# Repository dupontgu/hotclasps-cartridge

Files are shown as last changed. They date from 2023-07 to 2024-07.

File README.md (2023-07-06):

# HotClasps (HitClips compatible audio cartridge)
This repository contains the hardware, software, and enclosure CAD for the HotClaps cartridge (and accomanying debugger). It will play any audio through Tiger Electronics' [HitClips](https://en.wikipedia.org/wiki/HitClips) players.

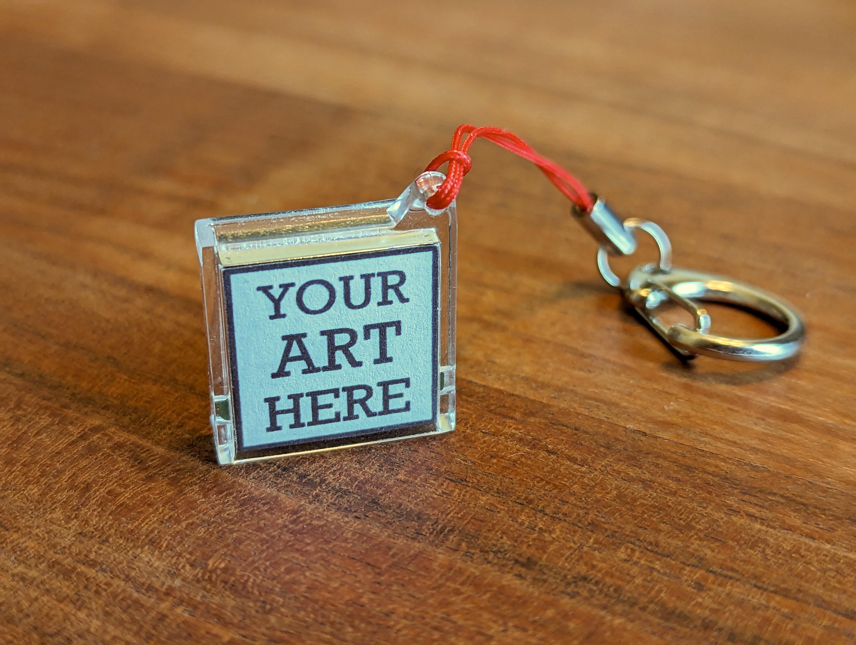
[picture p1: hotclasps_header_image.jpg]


### Context 
This is a complete rebuild of my [Homebrew HitClips](https://hackaday.io/project/183495-homebrew-hitclips) project from 2022.

### Features
* Significantly improved audio quality over the original toys (hard to quantify, but the bar was low).
* Space for ~10 minutes of audio, which can be split across multiple files. This can theoretically be extended if you dial back the audio quality further.
* USB Storage interface for dragging/dropping audio files from a computer.
* [Web application](https://www.hotclasps.com) with tools to convert audio files and print custom artwork for the case. (Source code for web app [here](https://github.com/dupontgu/hc-webapp))

### Notes
* The hardware is built around the Raspberry Pi RP2040 microcontroller.
* The firmware is written in [CircuitPython](https://circuitpython.org/), and features an audio driver written in [pioasm](https://rp2040pio-docs.readthedocs.io/en/latest/pio-programs.html).

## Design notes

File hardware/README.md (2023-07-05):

## Notes
* Cartridge is comprised of two PCBs - the main board, and an adapter which extends the thickness so that the cartridge makes direct contact with a HitClips player.
* Main board should be 0.8mm thick, adapter should be 1.2mm.

Front        |  Back
:-------------------------:|:-------------------------:
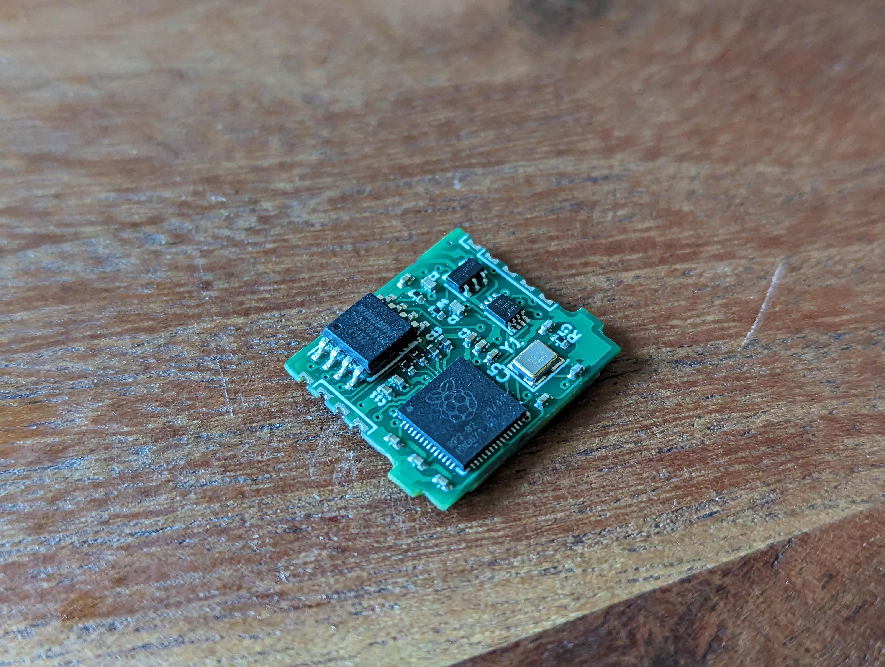
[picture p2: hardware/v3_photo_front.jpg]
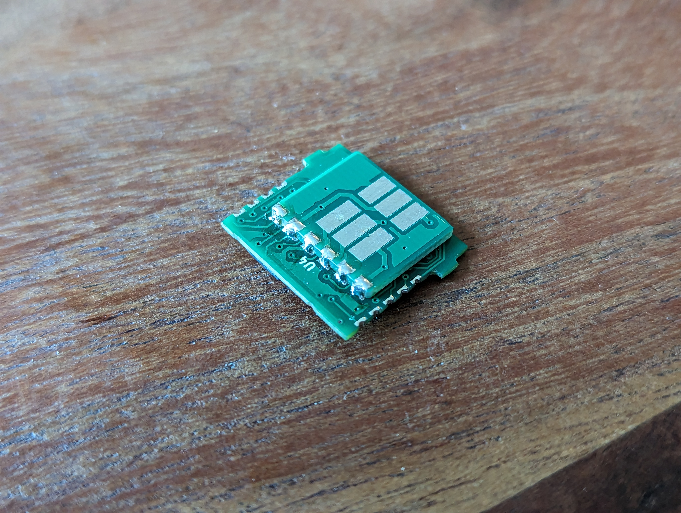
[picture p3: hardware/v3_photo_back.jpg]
  |

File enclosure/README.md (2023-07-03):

## Notes
* Cases are ordered from PCBWAY with their [UTR-8100 transparent resin](https://www.pcbway.com/rapid-prototyping/3d-printing/plastic/resin/UTR-8100/).
* The shim holds the circuit board securely in place within in the case, and also holds the artwork against the case window. It can be 3D printed / milled from any rigid material. (I use FDM-printed PETG)

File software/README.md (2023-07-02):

## Contents

## - `hotclasps_circuitpy_8_1_0.uf2`
This is the "officially" supported build of CircuitPython that runs on the HotClasps cartridge. It is based off of the `8.1.0` release, and simply adds a board definition with proper pin names and USB ids for this device.

## - `code.py`
The firmware for this device, which runs on the build of CircuitPython above. 
### **Notes:**
* This build expects audio files to be converted into the [`.htclp`](https://www.hotclasps.com/upload) format and loaded into a directory named `sounds`.
* CircuitPython dependencies:
    * [adafruit_pioasm](https://github.com/adafruit/Adafruit_CircuitPython_PIOASM)
    * [adafruit_ticks](https://github.com/adafruit/Adafruit_CircuitPython_Ticks)
    * [asyncio](https://github.com/adafruit/Adafruit_CircuitPython_asyncio)

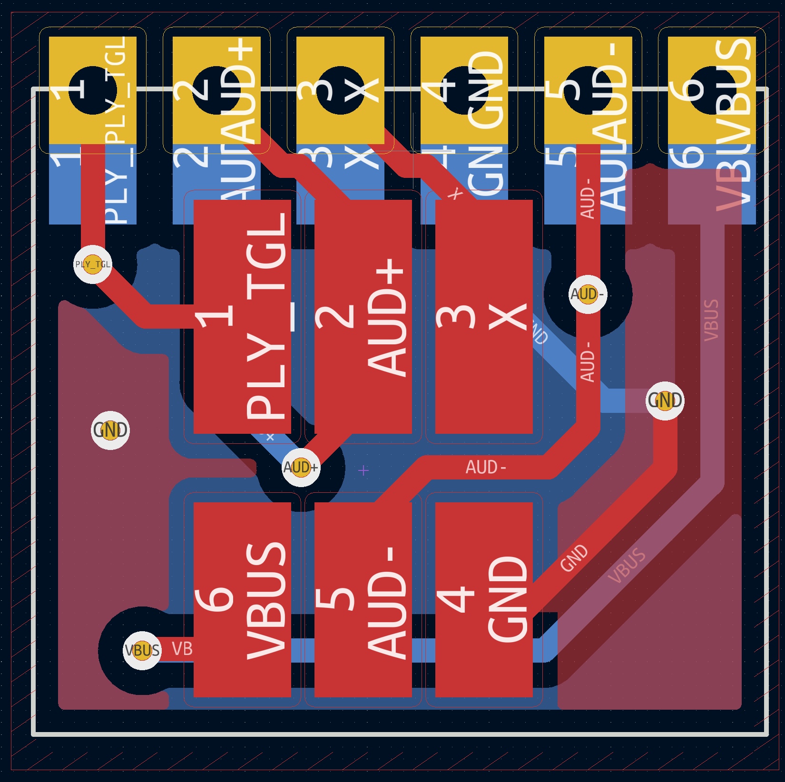
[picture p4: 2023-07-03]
hardware/hotclasps_v3_adapter.jpg

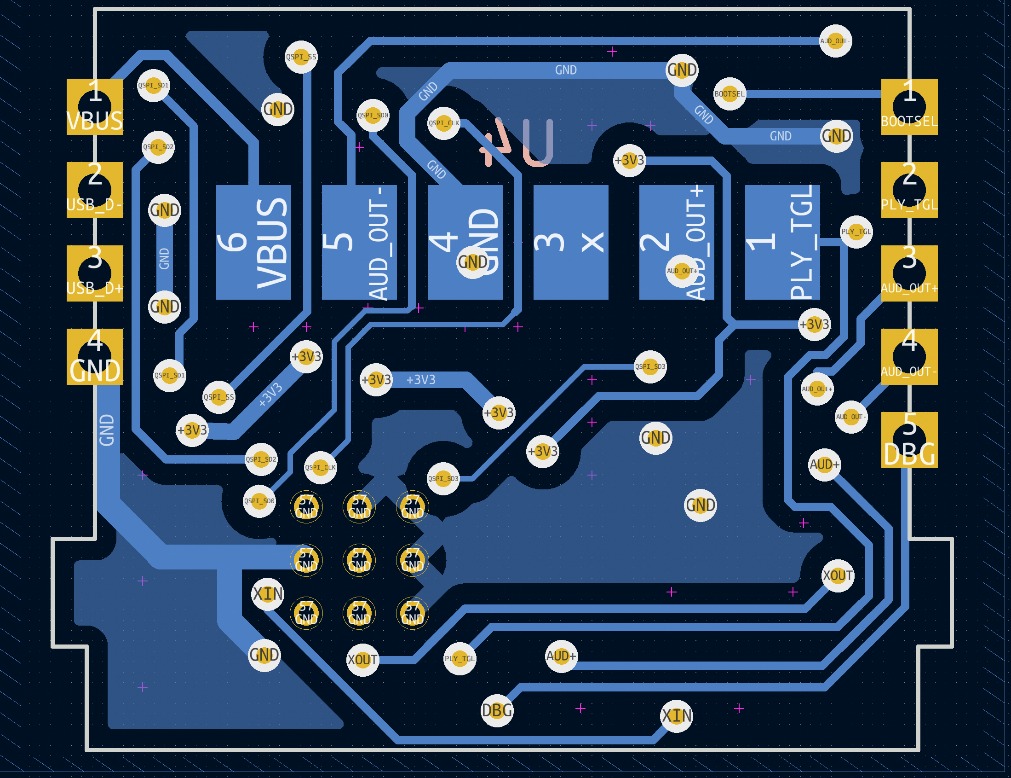
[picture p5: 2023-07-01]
hardware/hotclasps_v3_brd_back.png

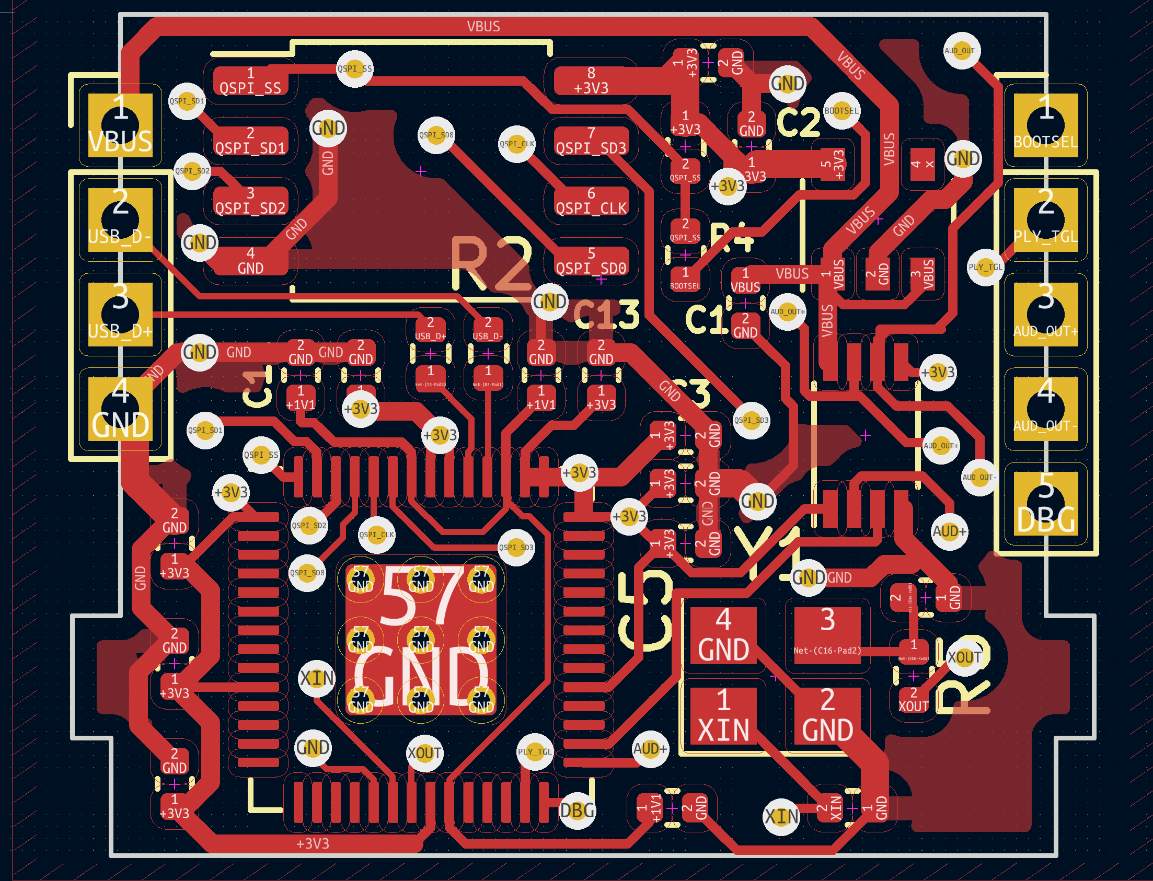
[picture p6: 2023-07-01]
hardware/hotclasps_v3_brd_front.png

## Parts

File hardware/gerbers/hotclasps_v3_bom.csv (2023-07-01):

Designator | Footprint | Comment
U2 | SOIC-8_5.23x5.23mm_P1.27mm | W25Q128JVS
C14,C9,C11,C5,C7,C3,C6,C4,C10,C8 | C_0402_1005Metric | 100n
R3 | R_0402_1005Metric | 10k
R5,R4 | R_0402_1005Metric | 1k
R1,R2 | R_0402_1005Metric | 27.4
C15,C16 | C_0402_1005Metric | 27p
U1 | TSOP-5_1.65x3.05mm_P0.95mm | NCP511SN33T1G
C13,C12 | C_0402_1005Metric | 1u
Y1 | Crystal_SMD_3225-4Pin_3.2x2.5mm | Crystal_GND24_Small
J1 | PinHeader_1x04_P2.00mm_Vertical | Conn_01x04_Male
C1,C2 | C_0402_1005Metric | 10u
U3 | RP2040-QFN-56 | RP2040
U5 | VSSOP-8_2.3x2mm_P0.5mm | 74LVCH2T45DC
J2 | PinHeader_1x05_P2.00mm_Vertical | Conn_01x05_Male
U4 | hitclip_2040_rcv | hitclip_6

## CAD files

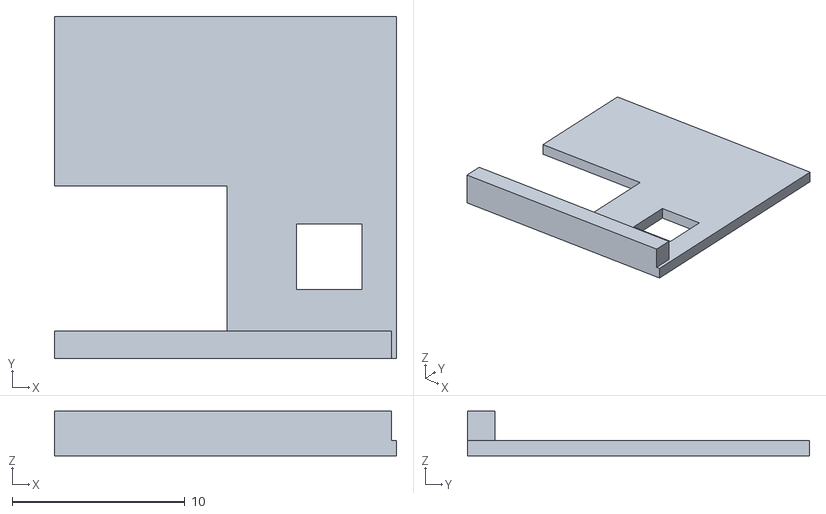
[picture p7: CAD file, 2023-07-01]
enclosure/hotclasps_shim_v2.stl
19.8 x 19.8 x 2.60

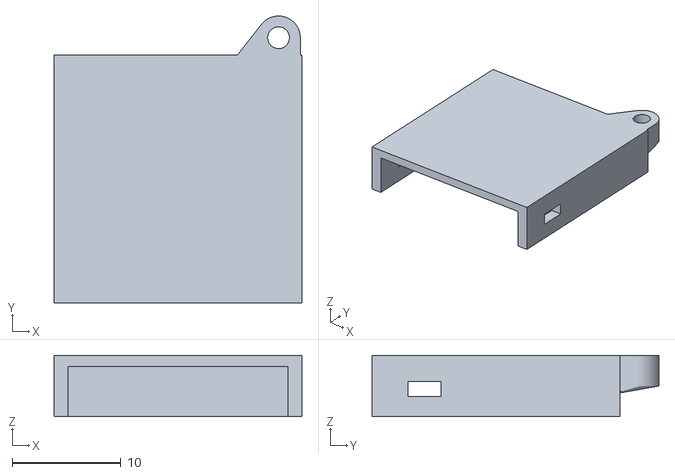
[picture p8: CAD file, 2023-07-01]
enclosure/hotclasps_case_v3.stl
22.8 x 26.4 x 5.63

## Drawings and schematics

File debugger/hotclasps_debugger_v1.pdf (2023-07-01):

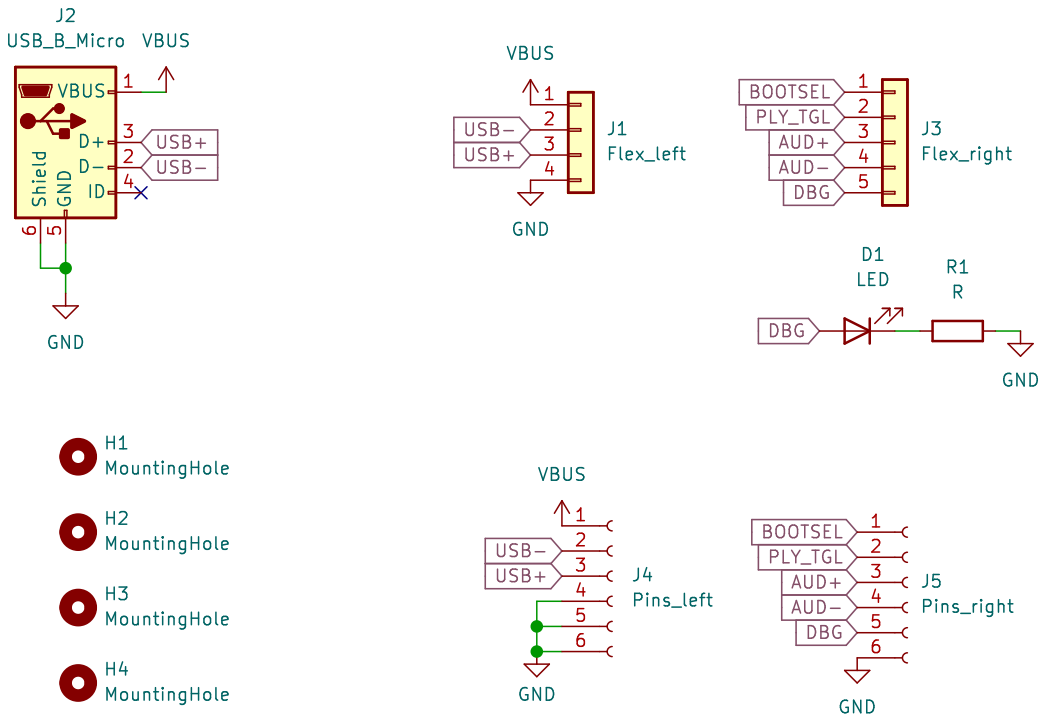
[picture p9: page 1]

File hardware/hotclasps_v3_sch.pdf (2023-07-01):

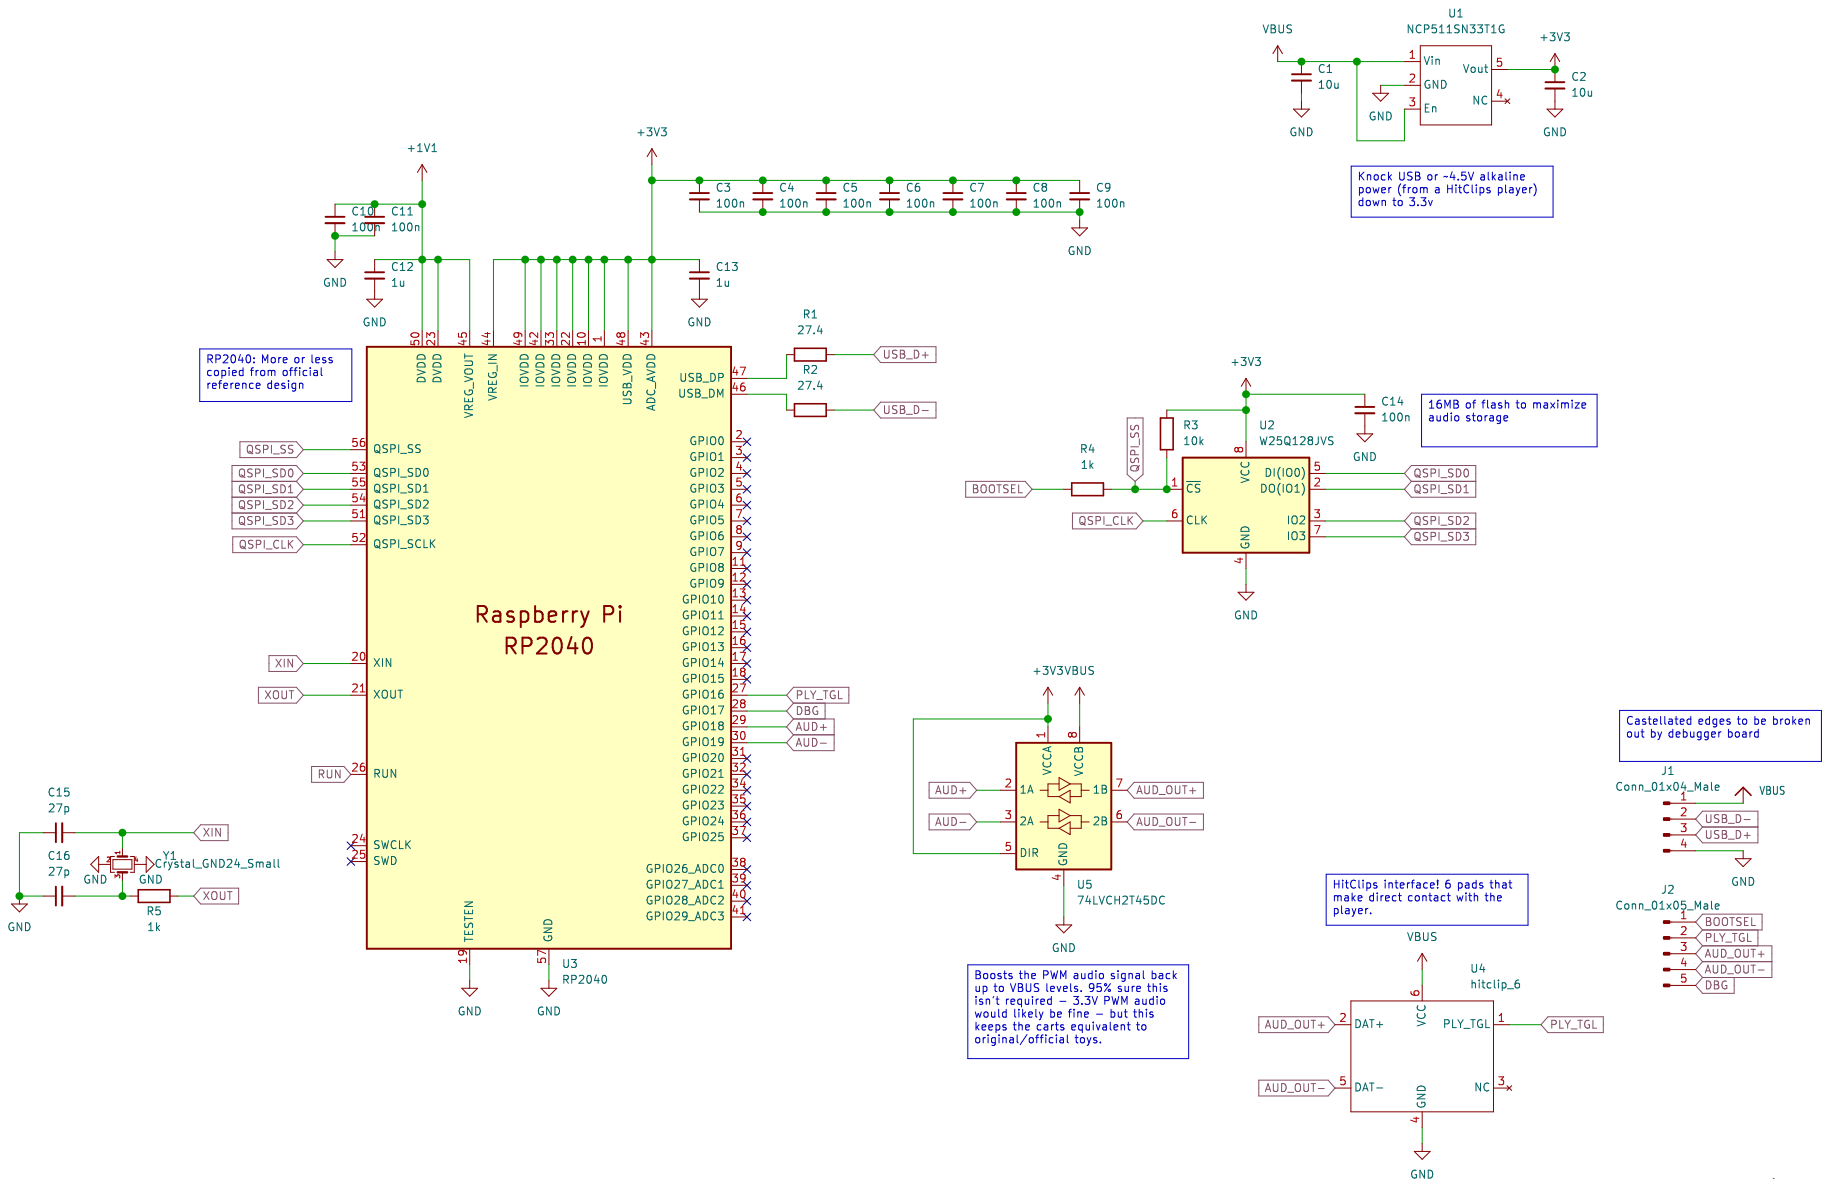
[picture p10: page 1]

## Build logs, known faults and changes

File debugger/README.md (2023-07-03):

## Notes
* The debugger is a passive PCB that breaks out the pins from the [main cartridge PCB](../hardware/) using [FlexiPins](https://www.solder.party/docs/flexypin/).
* Includes:
    * Micro-USB port
    * LED hooked up to the cartridge's debug pin
    * standard 2.54 headers for all pins

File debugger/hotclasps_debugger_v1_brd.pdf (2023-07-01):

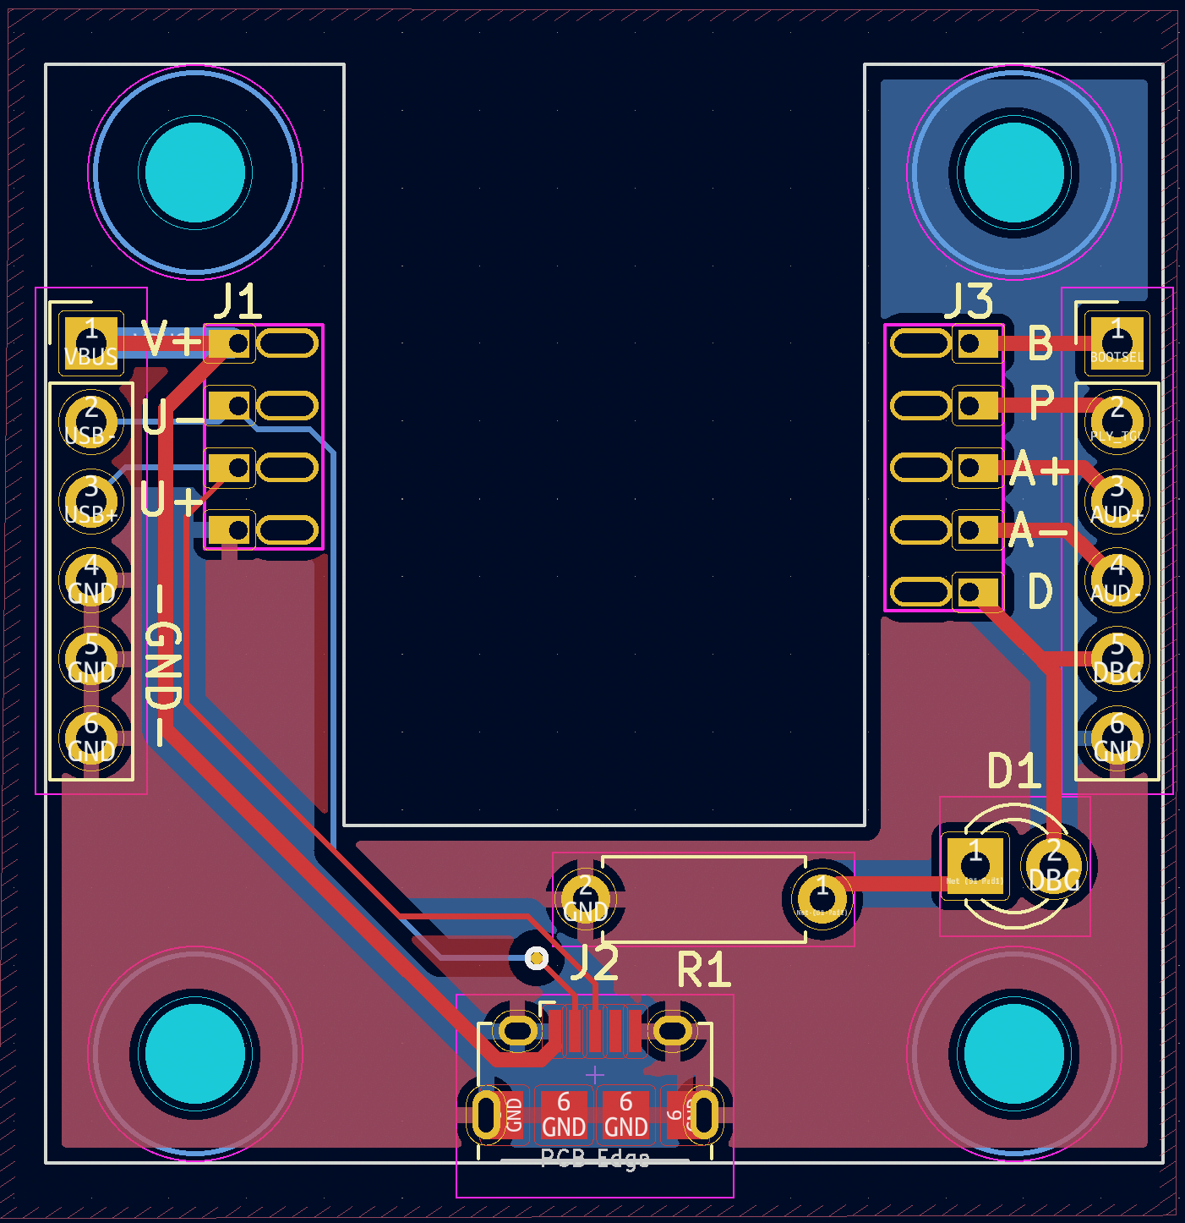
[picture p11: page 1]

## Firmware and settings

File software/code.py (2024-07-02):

import board
import rp2pio
import adafruit_pioasm
import time
import array
import gc
import os
import alarm
from digitalio import DigitalInOut, Direction, Pull

# Audio output PIO
# output each sample as PWM
# MSB determines which of 2 pins the PWM is routed
hc_output = """
.program hc_output
pull
mov isr, osr
start:
    jmp !osre main_loop
    pull
main_loop:
    mov x, y
    mov y, isr
    set pins, 0b11
    out x, 1
    jmp !x pos_pulse
    out x, 7
neg_loop:
    jmp x!=y neg_skip
    set pins, 0b010
neg_skip:
    jmp y-- neg_loop
    jmp start
pos_pulse:
    out x, 7
pos_loop:
    jmp x!=y pos_skip
    set pins, 0b001
pos_skip:
    jmp y-- pos_loop
    jmp start
"""

audio_state_machine = None  

BUFF_SIZE = 16384 * 2
NUM_CHUNKS = 32
SLEEP_THRESHOLD = 800

btn = DigitalInOut(board.PLAY_BTN)
btn.direction = Direction.INPUT
btn.pull = Pull.UP

dbg = DigitalInOut(board.DBG)
dbg.direction = Direction.OUTPUT

woken_from_sleep = alarm.wake_alarm is not None

# blink the debug led [err_code] number of times, repeatedly to signal a "crash"
def die(err_code):
    global dbg
    while True:
        for i in range(err_code):
            dbg.value = True
            time.sleep(0.15)
            dbg.value = False
            time.sleep(0.15)
        time.sleep(1)

sounds_dir = "sounds"

if not sounds_dir in os.listdir():
    die(4)

sounds = []
for s in os.listdir(sounds_dir):
    # don't play hidden files - macos likes to add junk files if you drag/drop from finder
    if (s[0] != '.'):
        print(s)
        sounds.append(sounds_dir + "/" + s)

sounds.sort()
sound_count = len(sounds)
if sound_count == 0:
    die(3)
sound_index = 0

# VERY IMPORTANT
# garbage colletor might run during playback if not disabled and cause gaps
# since we are tightly managing an fixed-size audio buffer, disable and manage manually
gc.disable()

# instantiate audio buffer, and create a chunked "view" into it to make writing easier
# chunks let us do more frequent background writes to PIO
read_buf = bytearray(BUFF_SIZE)
mv = memoryview(read_buf)
chunks = []
chunk_size = int(BUFF_SIZE / NUM_CHUNKS)
for i in range(NUM_CHUNKS):
    chunks.append(mv[i * chunk_size : ((i+1) * chunk_size)])
fifo_wrap = array.array('L', b"\x7f\x00\x00\x00")

debounce_reset = True

def init_sm():
    global audio_state_machine
    if audio_state_machine:
        audio_state_machine.stop()
        audio_state_machine.deinit()
    audio_state_machine = rp2pio.StateMachine(
        program = adafruit_pioasm.assemble(hc_output),
        frequency = 25100000,
        first_set_pin=board.AUDIO_P,
        initial_out_pin_direction=0b11,
        out_shift_right=False,
        initial_set_pin_state = 0b0000,
        set_pin_count = 2,
    )   
    audio_state_machine.restart()
    audio_state_machine.write(fifo_wrap)

# poll if user is pressing the button to stop the audio
def check_for_stop():
    global debounce_reset
    if not debounce_reset and btn.value:
        debounce_reset = True
    if (not btn.value and debounce_reset):
        print("stopping..")
        audio_state_machine.stop()
        while not btn.value:
            time.sleep(0.05)
            pass
        return True
    return False

def debug_blink(times):
    for _ in range(times):
        dbg.value = True
        time.sleep(0.10)
        dbg.value = False
        time.sleep(0.10)

while True:
    sleep_counter = 0
    sound = sounds[sound_index]
    sound_index = (sound_index + 1) % sound_count
    print(f'loading {sound}')
    debug_blink(1 if woken_from_sleep else 2)
    with open(sound,'rb') as fp:
        # once sound is ready, wait for user to hit play button
        # if `woken_from_sleep`, we know that they have already pressed it
        # if they dont press by `SLEEP_THRESHOLD`, go to sleep
        while btn.value and not woken_from_sleep:
            sleep_counter += 1
            if sleep_counter >= SLEEP_THRESHOLD:
                sleep_counter = 0
                btn.deinit()
                time.sleep(0.3)
                btn_pin = alarm.pin.PinAlarm(pin=board.PLAY_BTN, value=False, edge=True, pull=True)
                time.sleep(0.3)
                alarm.exit_and_deep_sleep_until_alarms(btn_pin)
            time.sleep(0.01)
            pass
        init_sm()
        woken_from_sleep = False
        debounce_reset = False
        print("playing")
        ## multiple blank writes to ensure followups are properly queued.
        for _ in range(3):
            audio_state_machine.background_write(read_buf)
        while True:
            should_break = False
            for c in chunks:
                data = fp.readinto(c, chunk_size)
                if (not data or check_for_stop()):
                    should_break = True
                    audio_state_machine.restart()
                    break
                time.sleep(0.04)
            if (should_break):
                break
            audio_state_machine.background_write(read_buf)
        gc.collect()

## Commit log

2023-07-01 add all hardware files
    [hotclasps_case_v3.stl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]
2023-07-03 add adapter hardware
    [hotclasps_adapter_v3-B_Cu.gbl, hotclasps_adapter_v3-B_Mask.gbs, hotclasps_adapter_v3-B_Paste.gbp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]
2023-07-05 add board photos
2023-07-10 remove click when inserting cartridge?
2024-07-02 stop audio driver when were done reading data so theres no rewrites of last read data
